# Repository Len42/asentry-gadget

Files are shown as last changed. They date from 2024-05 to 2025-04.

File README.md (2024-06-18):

# asentry-gadget

## Device to warn of potential asteroid impacts

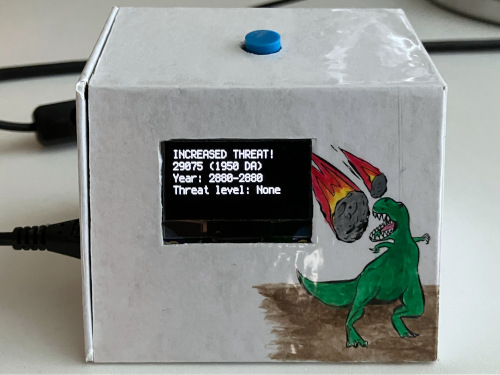
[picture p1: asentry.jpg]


This device uses a [Raspberry Pi Pico W](https://www.raspberrypi.com/documentation/microcontrollers/raspberry-pi-pico.html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)
and [CircuitPython](https://circuitpython.org/)
to monitor NASA JPL’s [Sentry](https://cneos.jpl.nasa.gov/sentry/) service and
warn of potential Earth-threatening asteroids.

[Click here for more info.](https://lenp.net/projects/asentry/)

If you want to do this on your computer instead of a stand-alone device,
[there’s a Python program for that.](https://github.com/Len42/asentry)

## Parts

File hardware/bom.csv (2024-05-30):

Qty | Description | Note | Datasheet | Manufacturer | ManufacturerPartNum | Distributor | DistributorPartNum | DistributorPartLink | Distributor2 | DistributorPartNum2 | DistributorPartLink2 | Distributor3 | DistributorPartNum3 | DistributorPartLink3
1 | Raspberry Pi Pico W |  | https://datasheets.raspberrypi.com/picow/pico-w-datasheet.pdf | Raspberry Pi | SC0918 | Adafruit | 5526 | https://www.adafruit.com/product/5526 | DigiKey | 2648-SC0918CT-ND | https://www.digikey.ca/en/products/detail/raspberry-pi/SC0918/16608263 | Mouser | 358-SC0918 | https://www.mouser.ca/ProductDetail/Raspberry-Pi/SC0918?qs=T%252BzbugeAwjj9dgdBLZSmdg%3D%3D
1 | Picowbell Proto for Pico |  | https://learn.adafruit.com/picowbell-proto | Adafruit | 5200 | Adafruit | 5200 | https://www.adafruit.com/product/5200 | DigiKey | 1528-5200-ND | https://www.digikey.ca/en/products/detail/adafruit-industries-llc/5200/16910842 | Mouser | 485-5200 | https://www.mouser.ca/ProductDetail/Adafruit/5200?qs=mELouGlnn3f6gH5dWr%2F%252BNQ%3D%3D
1 | OLED display, monochrome, 1.3in, 128x64, STEMMA QT |  | https://learn.adafruit.com/monochrome-oled-breakouts/overview | Adafruit | 938 | Adafruit | 938 | https://www.adafruit.com/product/938 | DigiKey | 1528-1512-ND | https://www.digikey.ca/en/products/detail/adafruit-industries-llc/938/5774238 | Mouser | 485-938 | https://www.mouser.ca/ProductDetail/Adafruit/938?qs=GURawfaeGuBw18l06EFBdw%3D%3D
1 | I2S amplifier BFF |  | https://learn.adafruit.com/i2s-amplifier-bff | Adafruit | 5770 | Adafruit | 5770 | https://www.adafruit.com/product/5770 | DigiKey | 1528-5770-ND | https://www.digikey.ca/en/products/detail/adafruit-industries-llc/5770/21283797 | Mouser | 485-5770 | https://www.mouser.ca/ProductDetail/Adafruit/5770?qs=mELouGlnn3c7KoTKMIBFjA%3D%3D
1 | Switch, pushbutton, momentary, SPST, normally open | Use any appropriate pushbutton switch
1 | Speaker, 4 or 8 ohms, 3 watts | Use any appropriate speaker | https://cdn-shop.adafruit.com/product-files/3968/H-23071740-02.pdf | Adafruit | 3968 | Adafruit | 3968 | https://www.adafruit.com/product/3968
1 | Cable, STEMMA QT / Qwiic JST SH, 4 pins | For the OLED display; length as required | https://cdn-shop.adafruit.com/product-files/4210/4210_Kaweei_CBH-100-04-100_cross_part_for_C13334-001.pdf | Adafruit | 4210 | Adafruit | 4210 | https://www.adafruit.com/product/4210 | DigiKey | 1528-4210-ND | https://www.digikey.ca/en/products/detail/adafruit-industries-llc/4210/10230021 | Mouser | 485-4210 | https://www.mouser.ca/ProductDetail/Adafruit/4210?qs=PzGy0jfpSMuCfezrcTX9rQ%3D%3D
1 | Cable, Molex PicoBlade, 2 pins | For the speaker; length as required | https://www.adafruit.com/product/3922 | Adafruit | 3922 | Adafruit | 3922 | https://www.adafruit.com/product/3922 | DigiKey | 1528-2732-ND | https://www.digikey.ca/en/products/detail/adafruit-industries-llc/3922/9685337 | Mouser | 485-3922 | https://www.mouser.ca/ProductDetail/Adafruit/3922?qs=byeeYqUIh0NmfRKg7Kt28Q%3D%3D
1 | USB cable, micro B | Used for firmware installation, and subsequently only for power
1 | Power supply, USB, 5V, 1 watt | Use any compatible power supply, or plug into a computer instead |  | Adafruit | 501 | Adafruit | 501 | https://www.adafruit.com/product/501
2 | Connector, pin header, 0.1 inch, 20 pins | For Pi Pico W (optional: additional connectors for cables) |  |  |  | Adafruit | 392 | https://www.adafruit.com/product/392 | DigiKey | 10129378-920001BLF-ND | https://www.digikey.ca/en/products/detail/amphenol-cs-fci/10129378-920001BLF/7915969 | Mouser | 649-1012937892001BLF | https://www.mouser.ca/ProductDetail/Amphenol-FCI/10129378-920001BLF?qs=0lQeLiL1qyYln8p37ftVpg%3D%3D
2 | Connector, socket header, 0.1 inch, 20 pins | For PiCowbell Proto (optional: additional connectors for cables) |  |  |  | Adafruit | 5583 | https://www.adafruit.com/product/5583 | DigiKey | 732-61304011821-ND | https://www.digikey.ca/en/products/detail/w%C3%BCrth-elektronik/61304011821/17737790 | Mouser | 710-61302011821 | https://www.mouser.ca/ProductDetail/Wurth-Elektronik/61302011821?qs=iLbezkQI%252Bsj8WCQQzMTU0A%3D%3D
 | Hookup wire | As required

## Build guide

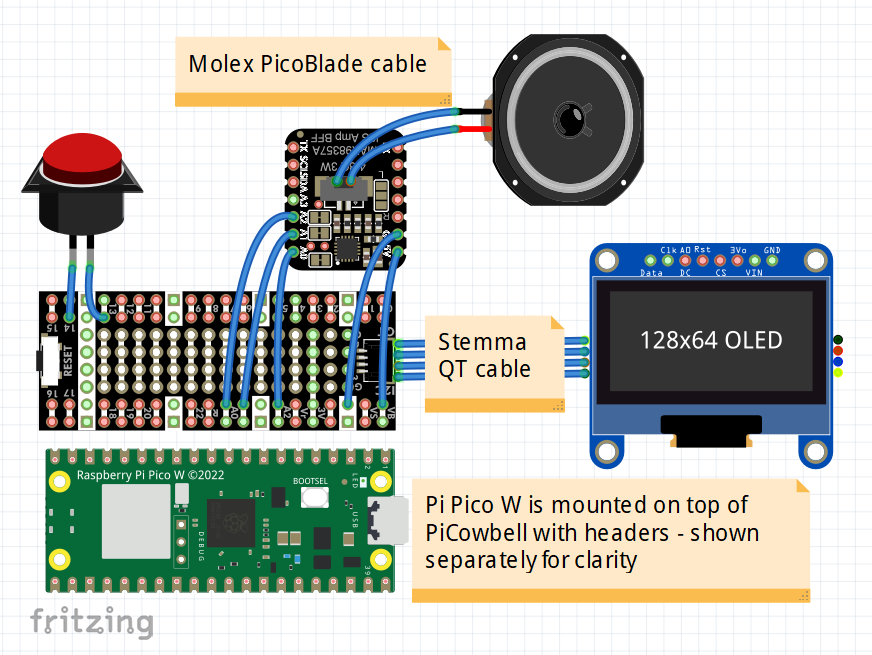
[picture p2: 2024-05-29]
hardware/wiring.png

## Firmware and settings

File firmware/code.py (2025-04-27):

""" Monitor the JPL Sentry database for asteroid impact threats.

    This is CircuitPython firmware to run on a Raspberry Pi Pico W.
    It downloads a list of potential Earth-threatening asteroids
    from NASA JPL's Sentry (https://cneos.jpl.nasa.gov/sentry/) service
    and displays an alert message if there are any new or increased threats.

    Copyright 2024 Len Popp
    Copyright 2023 Jeff Epler for Adafruit Industries (display code)
    See LICENSE file
"""
# type: ignore
import os
import ssl
import traceback
import gc

import board
import displayio
import keypad
import socketpool
import supervisor
from wifi import radio

import adafruit_requests
import adafruit_displayio_ssd1306
from adafruit_display_text import wrap_text_to_pixels
from adafruit_display_text.bitmap_label import Label
from adafruit_ticks import ticks_add, ticks_less, ticks_ms
from terminalio import FONT
import audiocore
import audiobusio

# Pin assignments for Pi Pico W
pin_switch = board.GP14 # pushbutton switch, low = pressed
pin_i2s_bclk = board.GP26 # I2S bit_clock
pin_i2s_wsel = board.GP27 # I2S word_select
pin_i2s_data = board.GP28 # I2S data

# Define the interval between data updates
check_interval = 1 * 60 * 60 # 1 hour in seconds

# Define idle display time
display_time = 10

# SSD1306 display setup
nice_font = FONT
line_spacing = 12 # in pixels
display_width = 128
display_height = 64
#  i2c display setup
displayio.release_displays()
oled_reset = board.GP9
# STEMMA I2C on picowbell
i2c = board.STEMMA_I2C()
display_bus = displayio.I2CDisplay(i2c, device_address=0x3D, reset=oled_reset)
display = adafruit_displayio_ssd1306.SSD1306(display_bus, width=display_width, height=display_height)


# WrappedTextDisplay class by jepler
class WrappedTextDisplay(displayio.Group):
    def __init__(self):
        super().__init__()
        self.offset = 0
        self.max_lines = display.height // line_spacing
        for i in range(self.max_lines):
            self.make_label("", i * line_spacing)
        self.lines = [""]
        self.text = ""

    def make_label(self, text, y):
        result = Label(
            font=nice_font,
            color=0xFFFFFF,
            background_color=0,
            line_spacing=line_spacing,
            anchor_point=(0, 0),
            anchored_position=(0, y),
            text=text)
        self.append(result)

    def add_text(self, new_text):
        print(end=new_text)
        if self.lines:
            text = self.lines[-1] + new_text
        else:
            text = new_text
        self.lines[-1:] = wrap_text_to_pixels(text, display.width, nice_font)
        self.scroll_to_end()

    def set_text(self, text):
        print("\n\n", end=text)
        self.text = text
        self.lines = wrap_text_to_pixels(text, display.width, nice_font)
        self.offset = 0

    def show(self, text):
        self.set_text(text)
        self.refresh()

    def add_show(self, new_text):
        self.add_text(new_text)
        self.refresh()

    def scroll_to_end(self):
        self.offset = self.max_offset()

    def scroll_next_line(self):
        max_offset = self.max_offset()
        self.offset = (self.offset + 1) % (max_offset + 1)

    def max_offset(self):
        return max(0, len(self.lines) - self.max_lines)

    def on_last_line(self):
        return self.offset == self.max_offset()

    def refresh(self):
        lines = self.lines
        # update labels from wrapped text, accounting for scroll offset
        for i in range(len(self)):
            offset_i = i + self.offset
            if offset_i >= len(lines):
                text = ""
            else:
                text = lines[offset_i]
            if text != self[i].text:
                self[i].text = text
        # Actually update the display all at once
        display.refresh()


def wait_button_scroll_text(button: keypad.Keys, max_time: int = 0, screen_time: int = 0):
    """ Wait while scrolling the text display, until the button is pressed
        or max_time seconds has passed (if specified).
    """
    button.events.clear()
    now = ticks_ms()
    # NOTE: The wait time before scrolling is chosen so that my favourite alert
    # sound has time to finish before scrolling, because updating the display
    # messes up the audio output.
    scroll_wait_ms = 6000
    scroll_time = ticks_add(now, scroll_wait_ms if wrapped_text.on_last_line() else 1000)
    timeout = ticks_add(now, max_time * 1000)
    screen_timeout = ticks_add(now, screen_time * 1000)
    while True:
        if (event := button.events.get()) and event.pressed:
            break
        now = ticks_ms()
        if max_time and ticks_less(timeout, now):
            break
        if screen_time and ticks_less(screen_timeout, now):
            # Clear the screen to avoid burn-in
            wrapped_text.show('')
            screen_time = 0
        if wrapped_text.max_offset() > 0 and ticks_less(scroll_time, ticks_ms()):
            wrapped_text.scroll_next_line()
            wrapped_text.refresh()
            scroll_time = ticks_add(scroll_time,
                                scroll_wait_ms if wrapped_text.on_last_line() else 1000)

def fetch_latest_data() -> list:
    """ Fetch the most "interesting" objects from NASA JPL's Sentry service. """
    wrapped_text.show('\n\nFetching data\n')
    # Run garbage collection to (hopefully) reduce memory problems due to fragmentation
    gc.collect()
    # Use one of these query strings to select the data returned from Sentry:
    # 1. Fetch a few of the most threatening objects
    ps_min = -3 # minimum threat level
    sRequest = f'https://ssd-api.jpl.nasa.gov/sentry.api?ps-min={ps_min}'
    # 2. Fetch recently-updated objects above a certain threat level
    #ps_min = -5 # minimum threat level
    #days = 7 # how many days old
    #sRequest = f'https://ssd-api.jpl.nasa.gov/sentry.api?ps-min={ps_min}&days={days}'
    # 3. DEBUG: Invalid request
    #sRequest = f'https://lenp.net/x'
    with requests.get(sRequest) as response:
        if response.status_code != 200:
            raise Exception(f'Bad HTTP response: {response.status_code} {response.reason.decode()}')
        else:
            results = response.json()
    if (results['signature']['source'] != 'NASA/JPL Sentry Data API'
            or results['signature']['version'] != '2.0'):
        raise Exception('Unexpected data format')
    return results['data']
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

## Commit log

2024-05-23 add fritzing file
    [asentry.fzz]
2024-05-24 add BOM file from Fritzing
2024-05-25 modify the fritzing diagram
    [asentry.fzz]
2024-05-29 work on audio
    [asentry.fzz]
2024-05-30 BOM - completed
    [bom.csv]
2024-05-30 BOM - fixed :D
    [bom.csv]
2024-05-30 BOM - more!
    [bom.csv]
2024-05-30 BOM - add a note
    [bom.csv]
2024-06-03 code.py: adjust scroll delay to fix audio
    [code.py]
2024-06-19 code.py: auto reset after error
    [code.py]
2024-07-05 firmware: Include code for a couple of alternative Sentry queries
2025-03-31 firmware: Update CircuitPython libraries to latest version
